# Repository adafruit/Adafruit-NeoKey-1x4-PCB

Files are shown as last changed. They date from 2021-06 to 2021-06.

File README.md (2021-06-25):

## Adafruit NeoKey 1x4 QT I2C PCB

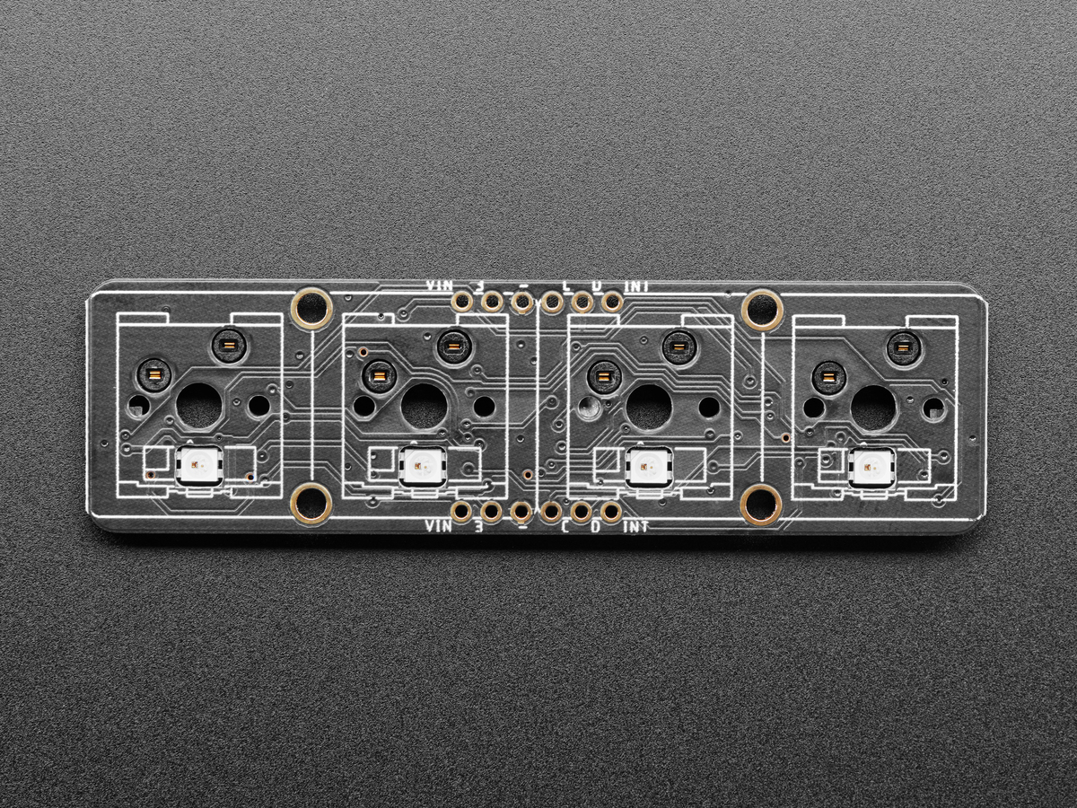
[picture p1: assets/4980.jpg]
<a href="http://www.adafruit.com/products/4980"><br/>
Click here to purchase one from the Adafruit shop</a>

PCB files for the Adafruit NeoKey 1x4 QT I2C. 

Format is EagleCAD schematic and board layout
* https://www.adafruit.com/product/4980

### Description

The only thing better than a nice mechanical key is, perhaps, FOUR mechanical keys that also can glow any color of the rainbow - and that's what the Adafruit NeoKey 1x4 QT I2C Breakout will let you do! This longgg 3" x 0.8" PCB fits four Cherry MX or compatible switches and make it easy to use with a breadboard/perfboard or with a STEMMA QT (Qwiic) connector for instant I2C connectivity on any platform.

Please note, each order comes with one assembled and programmed PCB but no switches or keycaps or microcontroller. Most folks have specific key switches and keycaps they want to include, this is just the controller board that plugs into a microcontroller.

The breakout has four Kailh sockets, which means you can plug in any MX-compatible switch instead of soldering it in. You may need a little glue to keep the switch in place: hot glue or a dot of epoxy worked fine for us. Each key also has a reverse-mount NeoPixel pointing up through the spot where many switches would have an LED to shine through.

A microcontroller is pre-programmed with our seesaw firmware so button presses and NeoPixel-controlling is done all over I2C. You can even connect multiple board by chaining the I2C and soldering closed the I2C address jumpers - with four jumpers you can have up to 16 of these boards on a single I2C bus. We have Arduino and CircuitPython/Python libraries for controlling the NeoKey 1x4's so you can use any microcontroller/computer for quick creation of a custom macropad.

You can also fit the breakouts onto a breadboard if you like - with two sets of breakout pads, there's plenty of flexibility for any kind of use. There are two rows of 6-pin contacts on a 0.1" grid on both sides. Solder in both sides for mechanical stability.

Soldering is required to attach the header for breadboard use, you may also need to solder jumpers closed to connect multiple boards together. A microcontroller is required to drive this board, it isn't stand-alone. Keys & keycaps are not included: Use any MX-compatible switch: Kailh, Gateron, etc all work!

### License

Adafruit invests time and resources providing this open source design, please support Adafruit and open-source hardware by purchasing products from [Adafruit](https://www.adafruit.com)!

Designed by Limor Fried/Ladyada for Adafruit Industries.

Creative Commons Attribution/Share-Alike, all text above must be included in any redistribution. 
See license.txt for additional details.

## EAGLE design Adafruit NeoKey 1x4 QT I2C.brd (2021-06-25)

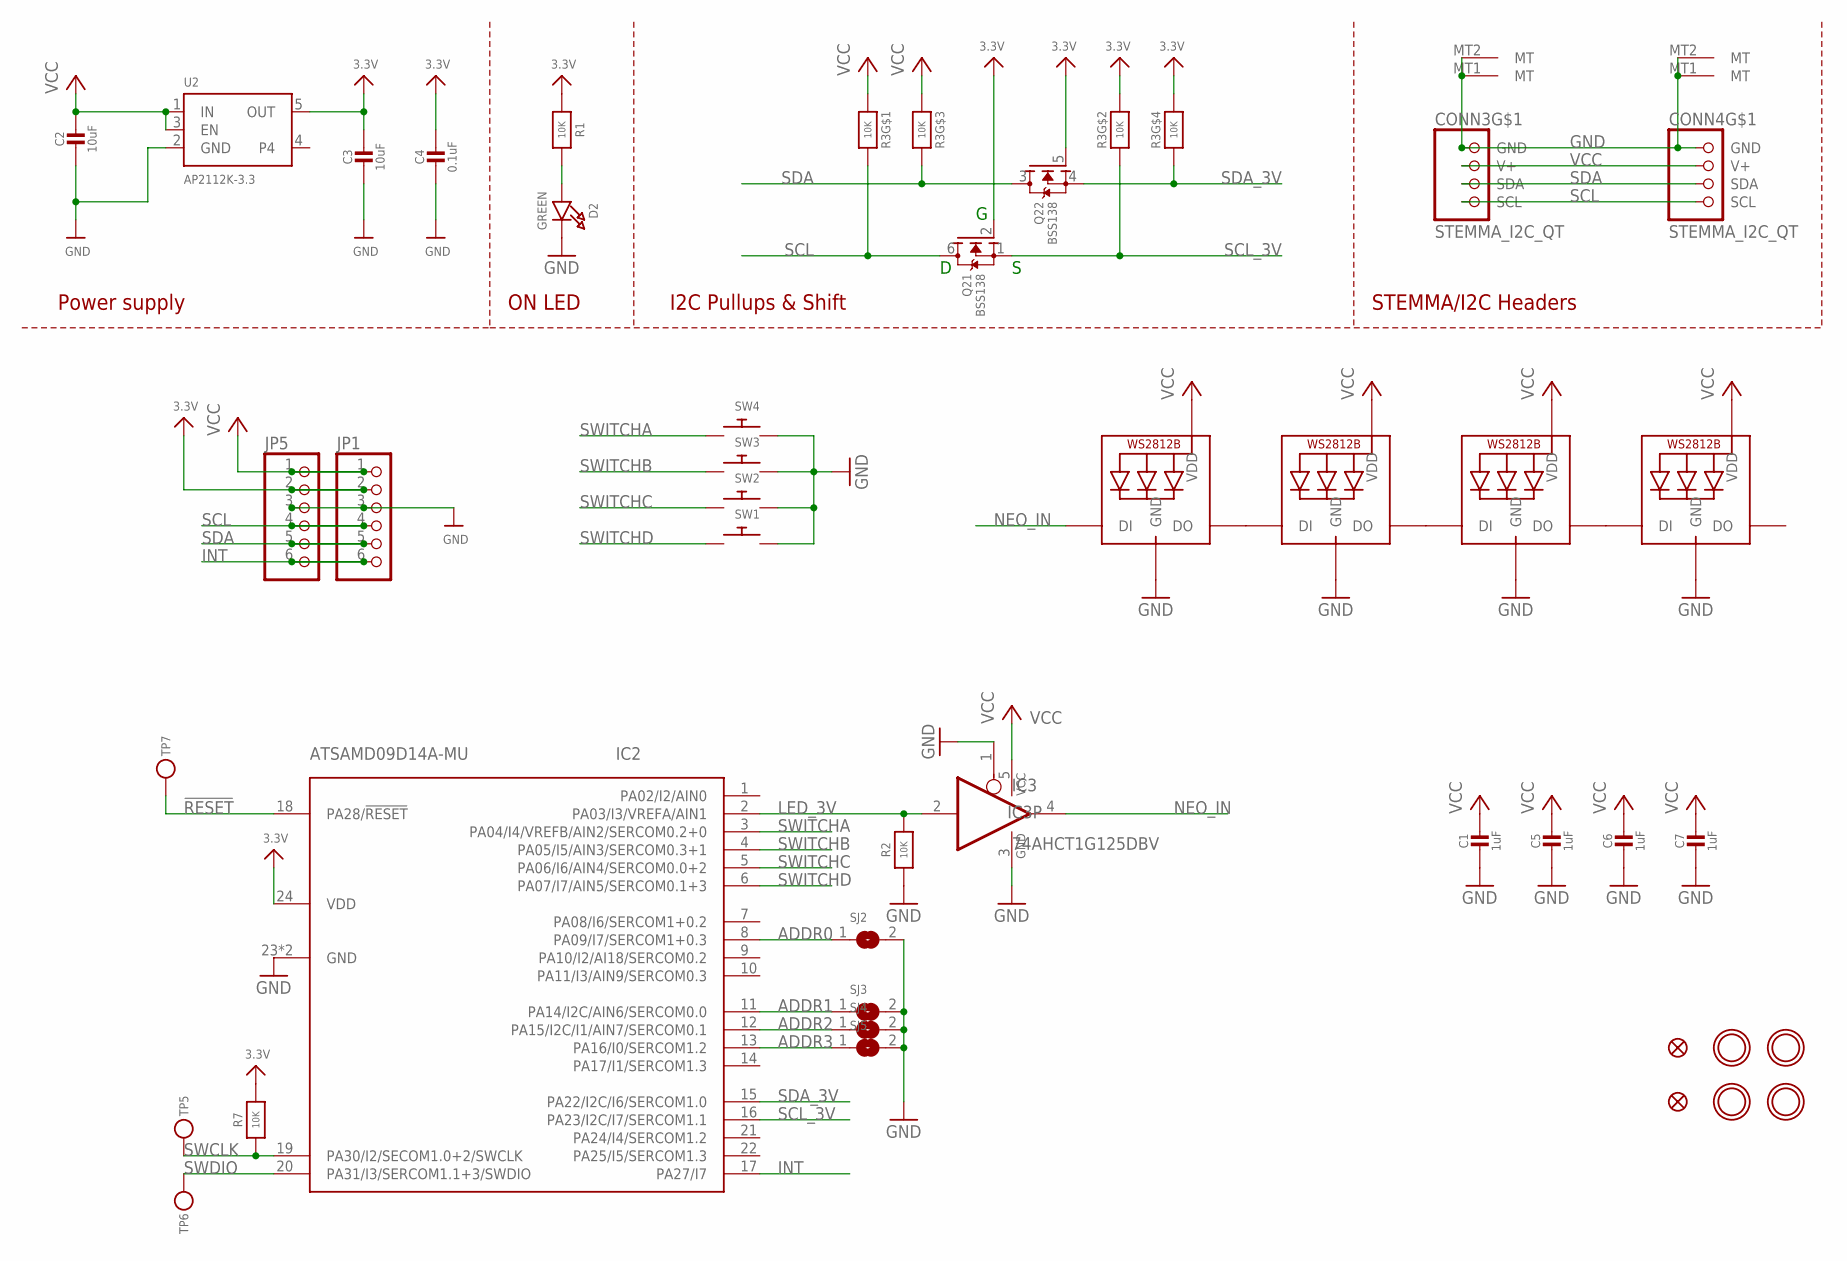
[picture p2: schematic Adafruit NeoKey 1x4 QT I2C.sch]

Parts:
C1, C5, C6, C7: 1uF; 0603-NO
C2, C3: 10uF; 0805-NO
C4: 0.1uF; 0603-NO
CONN3, CONN4: STEMMA_I2C_QT; JST_SH4
D2: GREEN; CHIPLED_0603_NOOUTLINE
FID1, FID2: FIDUCIAL_1MM
IC2: ATSAMD09D14A-MU; QFN24_4MM
IC3: 74AHCT1G125DBV; SOT23-5
JP1, JP5: HEADER-1X670MIL; 1X06_ROUND_70
LED1, LED2, LED3, LED4: WS2812B_SK6812E; NEO3535_REVERSE
Q2: BSS138; SOT363
R1, R2, R7: 10K; 0603-NO
R3: 10K; RESPACK_4X0603
SJ2, SJ3, SJ4, SJ5: SOLDERJUMPER; SOLDERJUMPER_ARROW_NOPASTE
SW1, SW2, SW3, SW4: SWITCH_PUSHBUTTON_KAILH_SOCKET; KAILH_SOCKET
TP5, TP6, TP7: TESTPOINTROUND1.5MM; TESTPOINT_ROUND_1.5MM
U2: AP2112K-3.3; SOT23-5
U$3, U$17, U$19, U$21: MOUNTINGHOLE2.5; MOUNTINGHOLE_2.5_PLATED

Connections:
3.3V: C3.1, C4.1, IC2.24 (VDD), JP1.2, JP5.2, Q2.2 (G), Q2.5 (G), R1.1, R3.2 (1), R3.4 (1), R7.2, U2.5 (OUT)
!RESET: IC2.18 (PA28/!RESET), TP7.P$1
ADDR0: IC2.8 (PA09/I7/SERCOM1+0.3), SJ2.1
ADDR1: IC2.11 (PA14/I2C/AIN6/SERCOM0.0), SJ3.1
ADDR2: IC2.12 (PA15/I2C/I1/AIN7/SERCOM0.1), SJ4.1
ADDR3: IC2.13 (PA16/I0/SERCOM1.2), SJ5.1
GND: C1.2, C2.2, C3.2, C4.2, C5.2, C6.2, C7.2, CONN3.1 (GND), CONN3.MT1 (MT), CONN3.MT2 (MT), CONN4.1 (GND), CONN4.MT1 (MT), CONN4.MT2 (MT), D2.C, IC2.23 (GND), IC2.THERM (GND), IC3.1 (OE), IC3.3 (GND), JP1.3, JP5.3, LED1.3-GND (GND), LED2.3-GND (GND), LED3.3-GND (GND), LED4.3-GND (GND), R2.1, SJ2.2, SJ3.2, SJ4.2, SJ5.2, SW1.1, SW2.1, SW3.1, SW4.1, U2.2 (GND)
INT: IC2.17 (PA27/I7), JP1.6, JP5.6
LED_3V: IC2.2 (PA03/I3/VREFA/AIN1), IC3.2 (I), R2.2
unnamed: D2.A, R1.2
unnamed: LED1.2-DOUT (DO), LED2.4-DIN (DI)
unnamed: LED2.2-DOUT (DO), LED3.4-DIN (DI)
unnamed: LED3.2-DOUT (DO), LED4.4-DIN (DI)
NEO_IN: IC3.4 (O), LED1.4-DIN (DI)
SCL: CONN3.4 (SCL), CONN4.4 (SCL), JP1.4, JP5.4, Q2.6 (D), R3.8 (2)
SCL_3V: IC2.16 (PA23/I2C/I7/SERCOM1.1), Q2.1 (S), R3.7 (2)
SDA: CONN3.3 (SDA), CONN4.3 (SDA), JP1.5, JP5.5, Q2.3 (D), R3.6 (2)
SDA_3V: IC2.15 (PA22/I2C/I6/SERCOM1.0), Q2.4 (S), R3.5 (2)
SWCLK: IC2.19 (PA30/I2/SECOM1.0+2/SWCLK), R7.1, TP5.P$1
SWDIO: IC2.20 (PA31/I3/SERCOM1.1+3/SWDIO), TP6.P$1
SWITCHA: IC2.3 (PA04/I4/VREFB/AIN2/SERCOM0.2+0), SW4.2
SWITCHB: IC2.4 (PA05/I5/AIN3/SERCOM0.3+1), SW3.2
SWITCHC: IC2.5 (PA06/I6/AIN4/SERCOM0.0+2), SW2.2
SWITCHD: IC2.6 (PA07/I7/AIN5/SERCOM0.1+3), SW1.2
VCC: C1.1, C2.1, C5.1, C6.1, C7.1, CONN3.2 (V+), CONN4.2 (V+), IC3.5 (VCC), JP1.1, JP5.1, LED1.1-VDD (VDD), LED2.1-VDD (VDD), LED3.1-VDD (VDD), LED4.1-VDD (VDD), R3.1, R3.3 (1), U2.1 (IN), U2.3 (EN)

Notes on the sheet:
I2C Pullups & Shift
STEMMA/I2C Headers
ON LED
Power supply

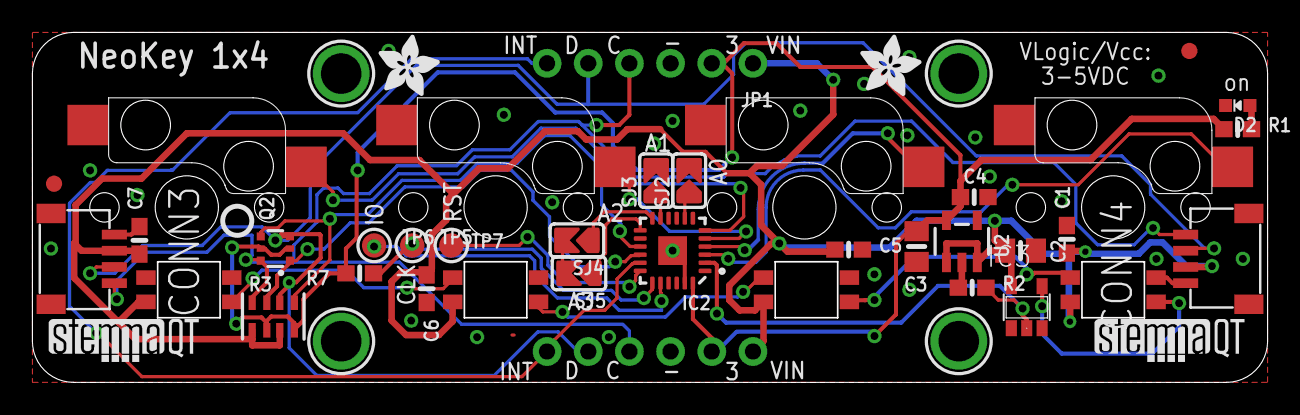
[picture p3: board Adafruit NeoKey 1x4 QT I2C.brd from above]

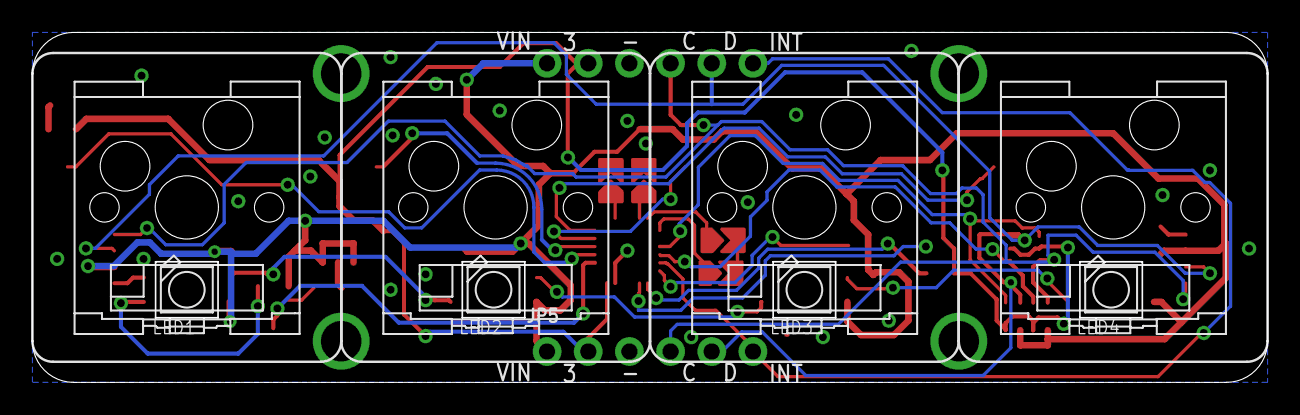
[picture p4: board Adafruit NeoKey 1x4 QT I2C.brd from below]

Board: 2 copper layers, 76.2 x 21.6 mm, 46 parts (9 on the bottom side), 25 nets.

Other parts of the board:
U$2, U$9: ADAFRUIT_3.5MM
U$25: PCBFEAT-REV-040
U$30, U$31: STEMMAQT

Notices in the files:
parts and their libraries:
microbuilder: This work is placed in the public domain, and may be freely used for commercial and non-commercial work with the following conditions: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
